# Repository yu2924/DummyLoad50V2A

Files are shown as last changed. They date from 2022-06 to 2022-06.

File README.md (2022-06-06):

# Dummy Load 50V2A

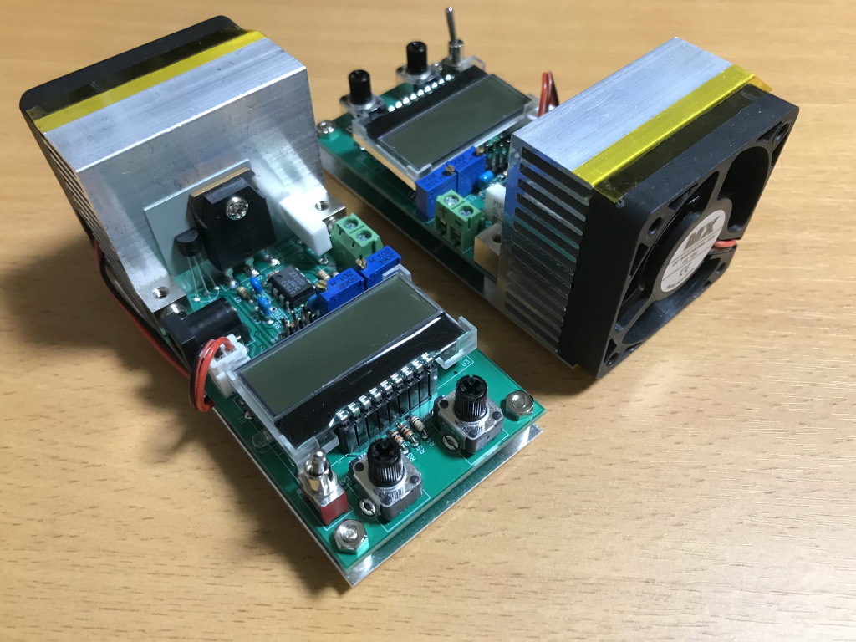
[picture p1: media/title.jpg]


ハードウェアプロジェクト**Dummy Load 50V2A**のデザインについてまとめます。

## 1. 概要

**Dummy Load 50V2A**は電源回路の負荷テストなどに便利な、定電流電子負荷装置です。
AVRマイコンを使用して電圧・電流・温度をモニタします。

* 最大定格DC50V、2A、50W程度
* 電圧モニタ分解能: 0.1V
* 電流モニタ分解能: 1mA
* 温度モニタ分解能: 1℃
* 電源: DC9～12V 100mA程度
* 動作中の電圧・電流・温度をモニタしながら、負荷電流をコース・ファインの2つのツマミで設定
* 負荷のON/OFFスイッチ

## 2. ツールとマテリアル

**ソフトウェアツール**
* 回路作図: [BSch3V](https://www.suigyodo.com/online/schsoft.htm) 0.83.05
* PCB設計: [KiCad](https://www.kicad.org/) 5.1
* ファームウェア開発: Atmel Studio 7 ([Microchip Studio 7](https://www.microchip.com/en-us/tools-resources/develop/microchip-studio))
* I2Cライブラリ: USI_TWI_Master ([TinyWireM](https://github.com/adafruit/TinyWireM))
* その他作図: [Inkscape](https://inkscape.org/) 1.1

**ハードウェアツール**
* AVRプログラマ: Atmel AVRISP mkIIまたは同等品
* 電圧計・電流計: 電圧と電流の読み取り値の比較基準に信頼できるものが必要です。とりあえず3 1/2桁のDMMでOKです。

**その他**
* ハンダとハンダゴテ、ニッパーとラジオペンチ、ヤスリ、タップとタップハンドル、等々
* スペーサー、ネジ、ワッシャー、アルミ板、等々

**※AVR開発環境のアップデート**
2022-05-31現在、AVRISP mkIIが既にディスコンということもあり、[MPLAB X IDE](https://www.microchip.com/en-us/tools-resources/develop/mplab-x-ide)と[MPLAB SNAP](https://www.microchip.com/en-us/development-tool/PG164100)への移行が良さそうです。Atmel Studioと同じ[Atmel AVR GNU Toolchain](https://www.microchip.com/en-us/tools-resources/develop/microchip-studio/gcc-compilers)も利用できるようです。

## 3. 回路の略解

[回路図](media/DummyLoad50V2A.pdf)

部品は概ね[秋月電子通商](https://akizukidenshi.com/)で購入できるものを中心に選んでいます。

**電子負荷**
オペアンプとMOSFETを使った電流シンクです。
オペアンプは単電源動作で0V入力できるものから広く選べますが、低オフセットのものが望ましいです。
MOSFETも特定の型番に限らず、定格電圧・電流、許容損失、熱抵抗、Vth(on)などの条件に見合ったものの中から広く選べると思います。

コース・ファインの2つのツマミで制御電圧を合成し、負荷電流を設定します。
回路図中480k～∞としている抵抗はオペアンプのオフセットを相殺するためのオプションであり、設定電流を0mAまで絞り込めない場合に追加します。

:bulb:このデザインは定電流負荷ですが、別のアイデアとして基準電圧をターゲット端子から取れば負荷電流が電圧に比例するオーム負荷となります。

**モニタ**
0～50Vの範囲を0.1Vの分解能で表示、オフセット調節を省略可、という条件で部品を選定しました。

* [AVR ATtiny85](https://www.microchip.com/en-us/product/ATtiny85)
* [外付け16bit 2ch ADC MCP3426](https://www.microchip.com/en-us/product/MCP3426)
* [温度センサ MCP9700A](https://www.microchip.com/en-us/product/MCP9700A)
* [LCDモジュール AQM1602Y-FLW-FBW](https://akizukidenshi.com/catalog/g/gP-12619/)

外付けADCを電圧・電流に、内蔵ADCを温度センサにそれぞれ割り当てます。  
AVRマイコンをLCDモジュールの真下に配置するために実装高さを抑え、[丸ピンＩＣソケット RI-01S-SG/4.2SMT](https://akizukidenshi.com/catalog/g/gP-12368/)を基板に埋め込むように実装します。

**ファームウェア**
内蔵のUSIユニットをI2C動作させるために、TinyWireMライブラリに同梱のUSI_TWI_Masterを利用します。TinyWireMはArduinoのライブラリですが、USI_TWI_MasterはArduinoに依存しません。

**放熱**
ヒートシンクの選択は厳密な熱設計に基づくものではありません。市販の電子負荷装置の中で定格50～100W程度のものに注目し、ワット当たりに必要なサイズを大雑把に見積もったものです。
Amazonで購入した詳細不明なアルミ製ヒートシンクと5cm角の12V DCファンを使用して、強制空冷としています。DCファンは3Dプリンタ向けの製品のようでした。

## 4. 組み立て

[ケガキ図](drawings/draft.svg)

ベースには50×100mm、t=1.0のアルミ板を使用しています。

1. パワーMOSFET以外の部品を基板に実装する。
2. 50mm角のヒートシンクにはM3タップを立て、10mm角の垂直取付用ブロックを使って基板と繋ぐ。
3. パワーMOSFETをヒートシンクに取り付け、基板にはんだ付けする。
4. 50×100mmのアルミ板ベースの上に5mmスペーサーを併用して基板とヒートシンクを固定する。
5. ヒートシンクにファンをテープで固定し、基板へコネクタを繋ぐ。
6. AVRマイコンとLCDを順にソケットに挿し込む。
7. AVRライタをISPピンヘッダに接続し、電源を接続してファームウェアを書き込む。
8. 適当な電圧・電流源を接続し、信頼できる電圧・電流計と表示値が一致するように多回転トリマをそれぞれ調節する。

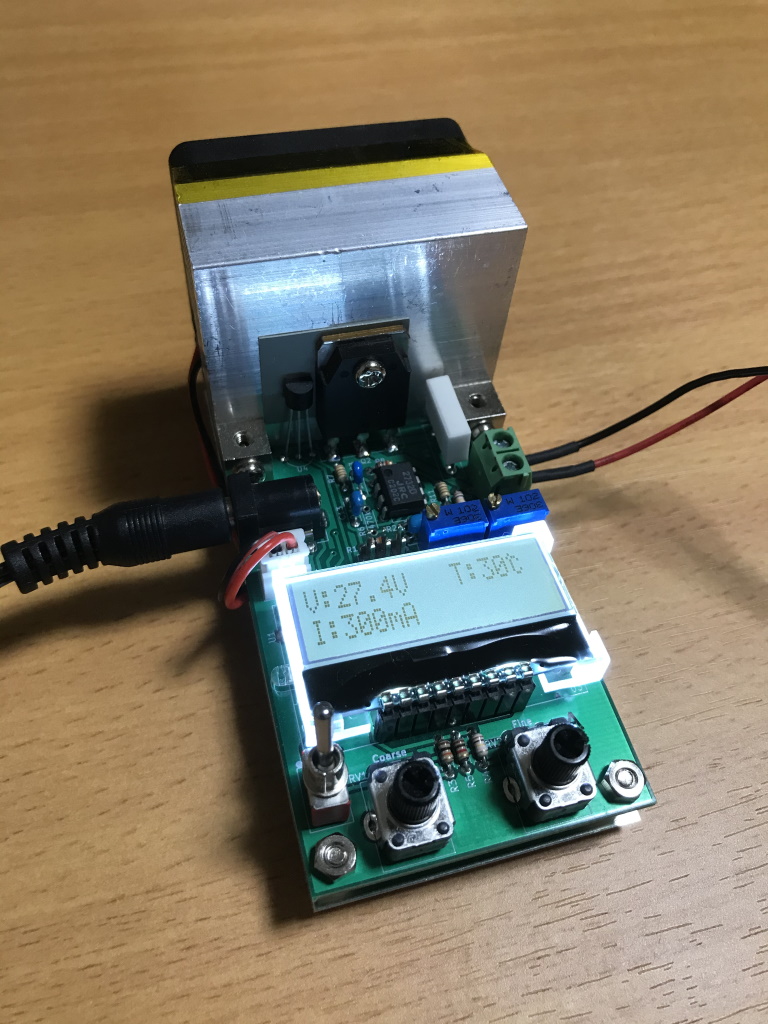
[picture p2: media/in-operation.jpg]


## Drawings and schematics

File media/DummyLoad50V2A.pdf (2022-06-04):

# Vdd VDD

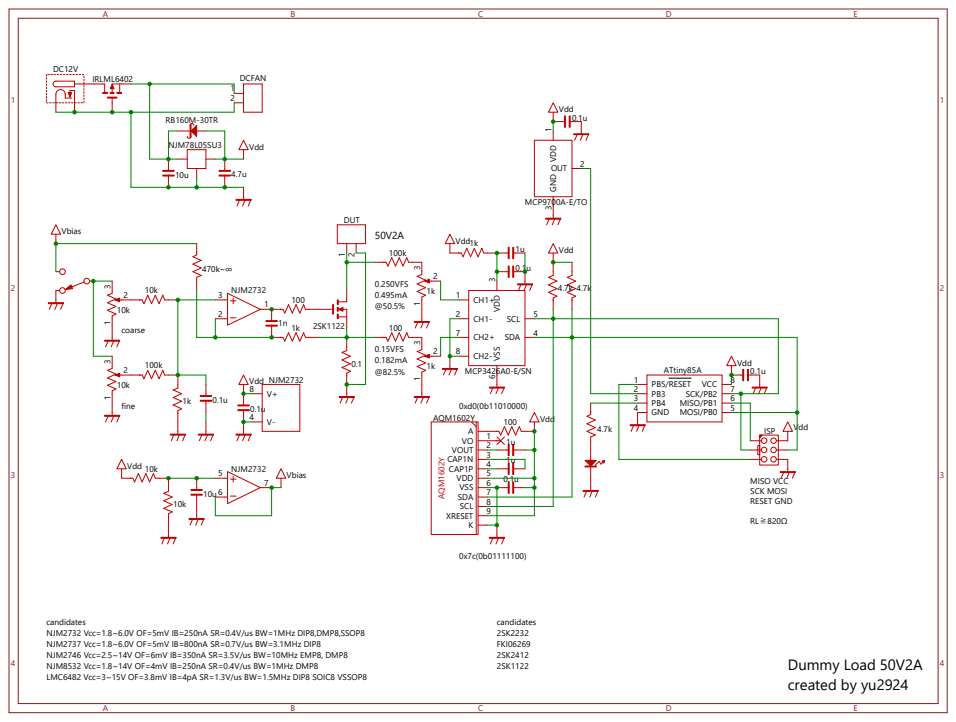
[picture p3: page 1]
Dummy Load 50V2A created by yu2924; MISO VCC SCK MOSI RESET GND; candidates 2SK2232 FKI06269 2SK2412 2SK1122; 0.250VFS 0.495mA @50.5%; 0.15VFS 0.182mA @82.5%; coarse; fine; IRLML6402; DCFAN; NJM78L05SU3; NJM2732; DUT; Vbias; Vdd 100k; Vdd; XRESET; SCL; SDA; VSS; VDD; CAP1P; CAP1N; VOUT; K AQM¹⁶⁰²Y; AQM1602Y; ISP; SDA 4; SCL 5 VDD; 3 VSS 6; MCP3426A0-E/SN; 1 GND; 3 OUT 2; MCP9700A-E/TO; 1k Vdd; Vdd NJM2732; VCC; PB5/RESET 1; GND 4; SCK/PB2; MISO/PB1; MOSI/PB0; ATtiny85A

candidates
NJM2732 Vcc=1.8~6.0V OF=5mV IB=250nA SR=0.4V/us BW=1MHz DIP8,DMP8,SSOP8
NJM2737 Vcc=1.8~6.0V OF=5mV IB=800nA SR=0.7V/us BW=3.1MHz DIP8
NJM2746 Vcc=2.5~14V OF=6mV IB=350nA SR=3.5V/us BW=10MHz EMP8, DMP8
NJM8532 Vcc=1.8~14V OF=4mV IB=250nA SR=0.4V/us BW=1MHz DMP8
LMC6482 Vcc=3~15V OF=3.8mV IB=4pA SR=1.3V/us BW=1.5MHz DIP8 SOIC8 VSSOP8

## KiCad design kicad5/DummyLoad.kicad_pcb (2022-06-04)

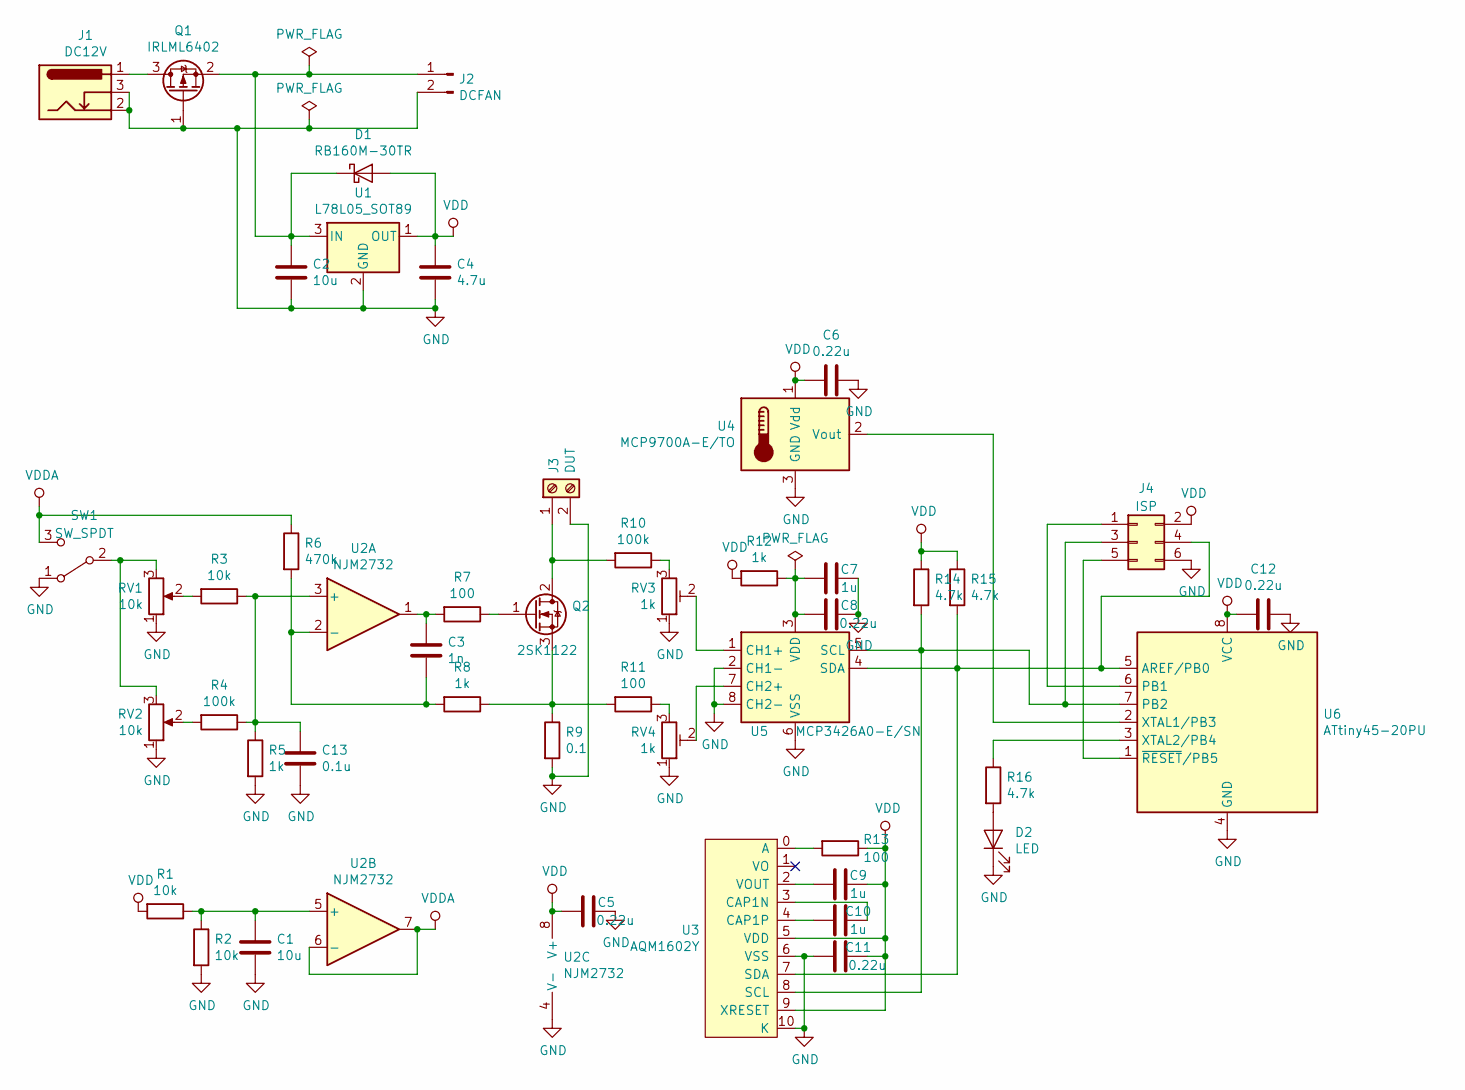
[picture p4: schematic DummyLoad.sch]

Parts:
C1: 10u; C_Disc_D4.7mm_W2.5mm_P5.00mm
C2: 10u; C_1206_3216Metric_Pad1.42x1.75mm_HandSolder
C3: 1n; C_Disc_D4.3mm_W1.9mm_P5.00mm
C4: 4.7u; C_0805_2012Metric_Pad1.15x1.40mm_HandSolder
C5, C6, C8, C11, C12: 0.22u; C_0603_1608Metric_Pad1.05x0.95mm_HandSolder
C7, C9, C10: 1u; C_0603_1608Metric_Pad1.05x0.95mm_HandSolder
C13: 0.1u; C_Disc_D4.3mm_W1.9mm_P5.00mm
D1: RB160M-30TR; D_SOD-123
D2: LED; LED_D3.0mm_Horizontal_O3.81mm_Z2.0mm
J1: DC12V; BarrelJack_Horizontal
J2: DCFAN; JST_XH_B2B-XH-A_1x02_P2.50mm_Vertical
J3: DUT; Terminal-2P
J4: ISP; PinHeader_2x03_P2.54mm_Vertical
Q1: IRLML6402; SOT-23
Q2: 2SK1122; TO-3P-3_Vertical
R1, R2, R3: 10k; R_Axial_DIN0204_L3.6mm_D1.6mm_P5.08mm_Horizontal
R4, R10: 100k; R_Axial_DIN0204_L3.6mm_D1.6mm_P5.08mm_Horizontal
R5, R8, R12: 1k; R_Axial_DIN0204_L3.6mm_D1.6mm_P5.08mm_Horizontal
R6: 470k; R_Axial_DIN0204_L3.6mm_D1.6mm_P5.08mm_Horizontal
R7, R11, R13: 100; R_Axial_DIN0204_L3.6mm_D1.6mm_P5.08mm_Horizontal
R9: 0.1; R_Box_L13.0mm_W4.0mm_P9.00mm
R14, R15, R16: 4.7k; R_Axial_DIN0204_L3.6mm_D1.6mm_P5.08mm_Horizontal
RV1, RV2: 10k; Potentiometer_Alps_RK09K_Single_Vertical
RV3, RV4: 1k; Potentiometer_Bourns_3296W_Vertical
SW1: SW_SPDT; SPDT-PCB
U1: L78L05_SOT89; SOT-89-3
U2: NJM2732; DIP-8_W7.62mm
U3: AQM1602Y
U4: MCP9700A-E/TO; TO-92_Inline_Wide
U5: MCP3426A0-E/SN; SOIC-8_3.9x4.9mm_P1.27mm
U6: ATtiny45-20PU; DIP-8_W7.62mm-LoProf

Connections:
GND: C1.2, C2.2, C4.2, C5.2, C6.2, C7.2, C8.2, C11.2, C12.2, C13.2, D2.1 (K), J1.2, J1.3, J2.2, J3.2, J4.6, Q1.1 (G), R2.2, R5.2, R9.2, RV1.0, RV1.1, RV2.0, RV2.1, RV3.1, RV4.1, SW1.1 (A), U1.2 (GND), U2.4 (V-), U3.6 (VSS), U3.10 (K), U4.3 (GND), U5.2 (CH1-), U5.6 (VSS), U5.8 (CH2-), U6.4 (GND)
unnamed: C1.1, R1.1, R2.1, U2.5 (+)
unnamed: C2.1, D1.1 (K), J2.1, Q1.2 (S), U1.3 (IN)
unnamed: C3.1, R7.2, U2.1
unnamed: C3.2, R6.2, R8.2, U2.2 (-)
unnamed: C7.1, C8.1, R12.1, U5.3 (VDD)
unnamed: C9.2, U3.2 (VOUT)
unnamed: C10.1, U3.3 (CAP1N)
unnamed: C10.2, U3.4 (CAP1P)
unnamed: C13.1, R3.1, R4.1, R5.1, U2.3 (+)
unnamed: D2.2 (A), R16.2
unnamed: J1.1, Q1.3 (D)
unnamed: J3.1, Q2.2 (D), R10.2
unnamed: J4.1, U6.6 (PB1)
unnamed: J4.3, R14.2, U3.8 (SCL), U5.5 (SCL), U6.7 (PB2)
unnamed: J4.4, R15.2, U3.7 (SDA), U5.4 (SDA), U6.5 (AREF/PB0)
unnamed: J4.5, U6.1 (~RESET~/PB5)
unnamed: Q2.1 (G), R7.1
unnamed: Q2.3 (S), R8.1, R9.1, R11.2
unnamed: R3.2, RV1.2
unnamed: R4.2, RV2.2
unnamed: R10.1, RV3.3
unnamed: R11.1, RV4.3
unnamed: R13.2, U3.0 (A)
unnamed: R16.1, U6.3 (XTAL2/PB4)
unnamed: RV1.3, RV2.3, SW1.2 (B)
unnamed: RV3.2, U5.1 (CH1+)
unnamed: RV4.2, U5.7 (CH2+)
unnamed: U4.2 (Vout), U6.2 (XTAL1/PB3)
VDD: C4.1, C5.1, C6.1, C9.1, C11.1, C12.1, D1.2 (A), J4.2, R1.2, R12.2, R13.1, R14.1, R15.1, U1.1 (OUT), U2.8 (V+), U3.5 (VDD), U3.9 (XRESET), U4.1 (Vdd), U6.8 (VCC)
VDDA: R6.1, SW1.3 (C), U2.6 (-), U2.7

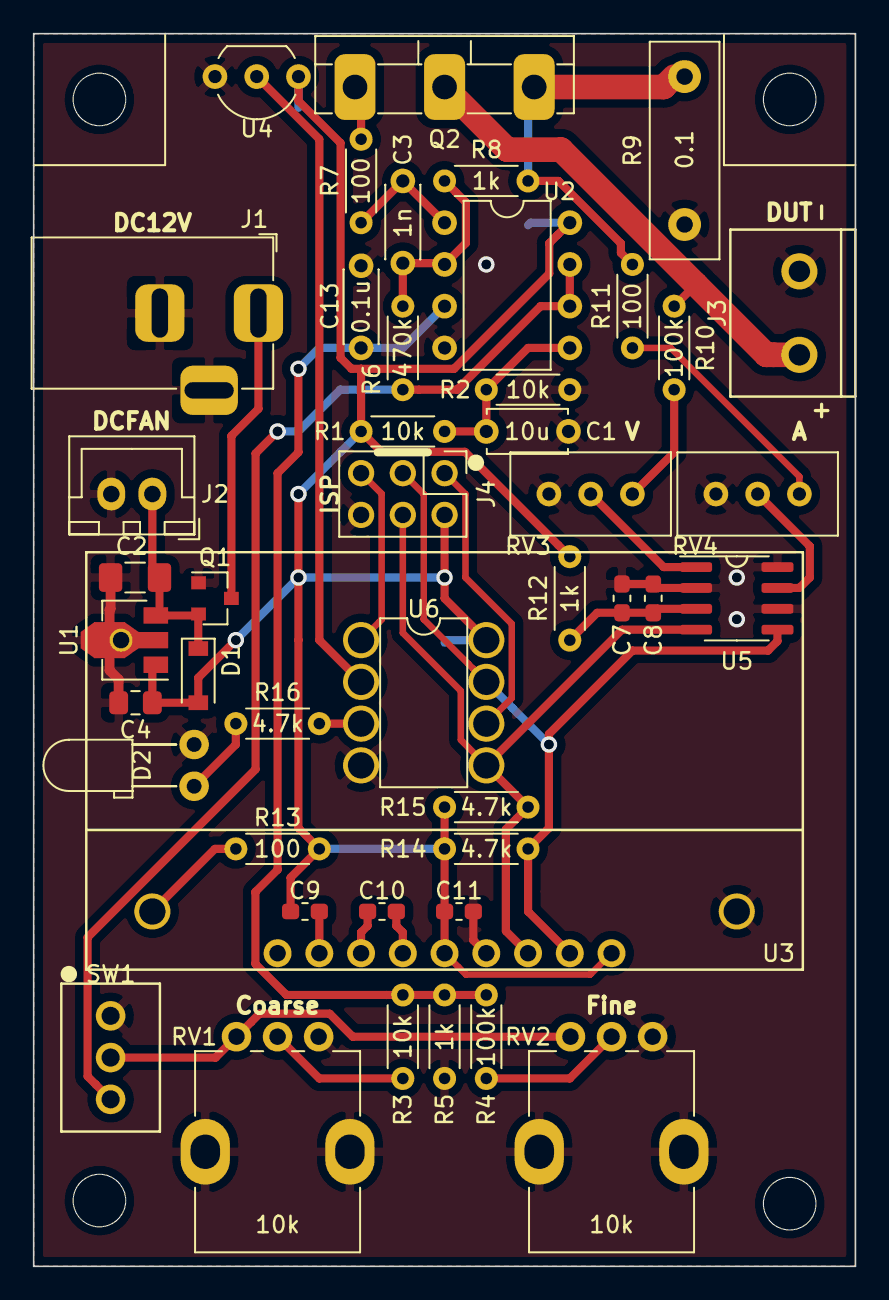
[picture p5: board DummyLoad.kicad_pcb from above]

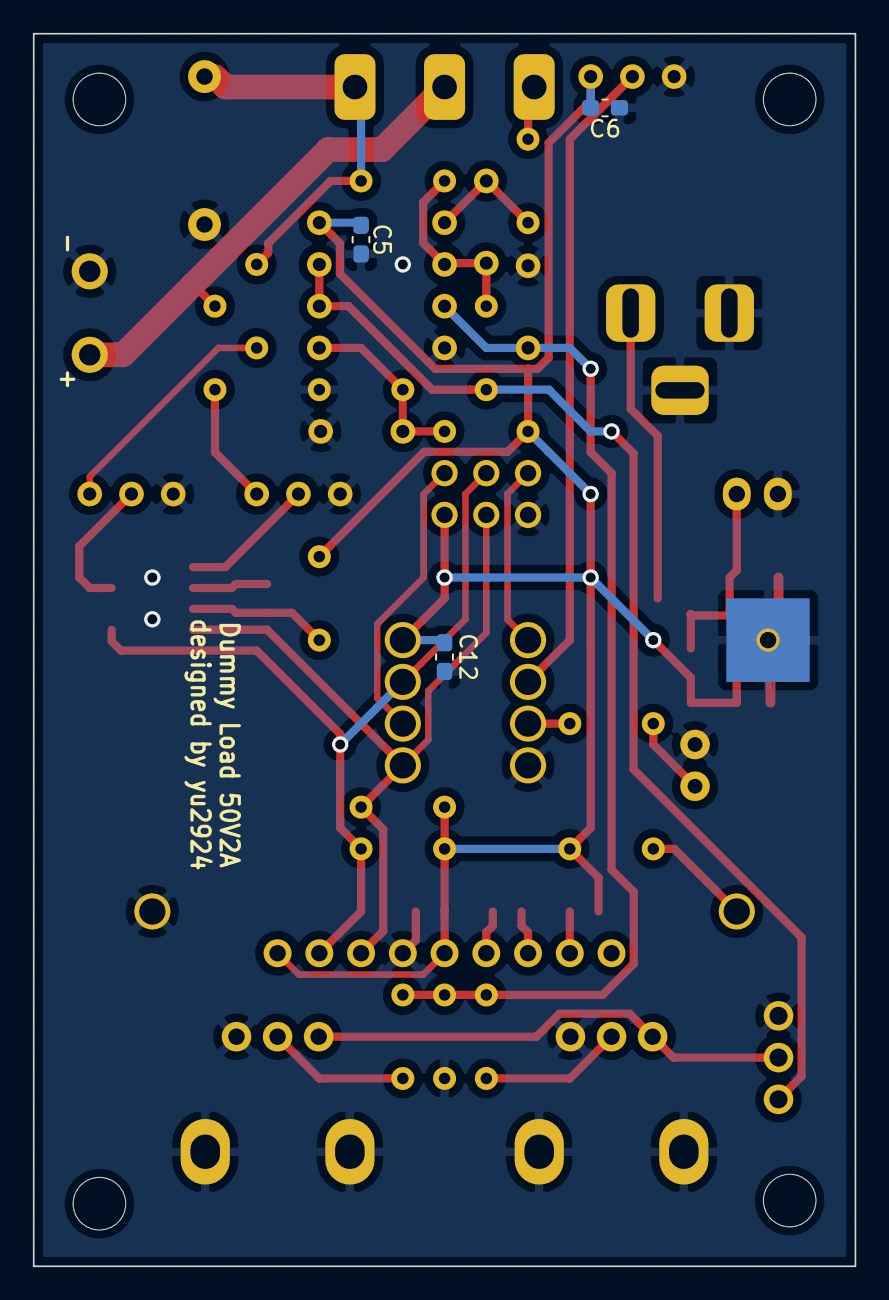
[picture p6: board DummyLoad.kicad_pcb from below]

Board: 2 copper layers, 50.0 x 75.0 mm, 48 parts (3 on the bottom side), 31 nets.

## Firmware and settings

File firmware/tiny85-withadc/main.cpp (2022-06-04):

/*
 * tiny85-withadc.cpp
 *
 * Created: 2019/08/12 0:39:17
 * Author : yu2924
 */ 

#include <avr/io.h>
#include <avr/interrupt.h>
#include <avr/sleep.h>
#include <util/delay.h>
// to use float with printf, requires linker options: -Wl,-u,vfprintf -lprintf_flt -lm
#include <stdio.h>
#include "USI_TWI_Master.h"
#include "MCP342x.h"
#include "ST7032i.h"

inline uint8_t getbit(volatile uint8_t& port, uint8_t bit) {return (port >> bit) & 0x01;}
inline void setbit(volatile uint8_t& port, uint8_t bit, uint8_t v) {port = (port & (uint8_t)~(1 << bit)) | (v << bit);}
	
inline int roundd2ip(double v) { return (int)(v + 0.5); }
inline int16_t absi16(int16_t v) { return (0 <= v) ? v : -v; }

struct AverageBuffer8ui
{
	uint16_t totalsum;
	uint8_t buffer[4];
	uint8_t pos;
	uint8_t push(uint8_t vnew)
	{
		uint8_t vlast = buffer[pos & 0x03];
		totalsum -= vlast;
		buffer[pos & 0x03] = vnew;
		totalsum += vnew;
		pos ++;
		return (uint8_t)(totalsum >> 2);
	}
};

struct AverageBuffer14i
{
	int16_t totalsum;
	int16_t buffer[4];
	uint8_t pos;
	int16_t push(int16_t vnew)
	{
		int16_t vlast = buffer[pos & 0x03];
		totalsum -= vlast;
		buffer[pos & 0x03] = vnew;
		totalsum += vnew;
		pos ++;
		return totalsum >> 2;
	}
};

#define LED_PORT PORTB
#define LED_BIT PB4

static const uint8_t CG_CDEG[] =
{
	0b00001000,
	0b00010110,
	0b00001001,
	0b00001000,
	0b00001000,
	0b00001001,
	0b00000110,
	0b00000000,
};

int main(void)
{
	// clock prescaler
	CLKPR = (1<<CLKPCE); // enable change
	CLKPR = (0b0000<<CLKPS0); // divisor=1 (8MHz)
	// PortB
	DDRB = (1<<DDB4); // LED output: PB4
	PORTB = (1<<PB5)|(1<<PB1); // pull-up enabled: unused pins PB1, PB5
	// ADC
	ADMUX = (0<<REFS0)|(1<<ADLAR)|(0<<REFS2)|(0b0011<<MUX0); // vref=Vcc, alignment=left-justified, mux=ADC3(PB3)
	ADCSRA = (1<<ADEN)|(0<<ADATE)|(0<<ADIF)|(0<<ADIE)|(0b110<<ADPS0); // ADC=enabled, auto-trigger=disabled, interrupt=disabled, prescaler=1/64 (125kHz)
	ADCSRB = (0<<BIN)|(0<<IPR)|(0b000<<ADTS0); // bipolar=no, polarity-reversal=no, triggersource=freerunning
	DIDR0 = (1<<ADC3D); // digital-input-disabled-ADC3(PB3)=yes
	// timer1
	TCCR1 = (1<<CTC1)|(0b1111<<CS10); // enable CTC, divisor=16384 (488.3Hz)
	GTCCR = 0;
	OCR1A = 24; // tick = 20.35Hz (fire interrupt)
	OCR1C = 24; // tick = 20.35Hz (reset counter)
	TIMSK = (1<<OCIE1A); // enable interrupt
	PLLCSR = 0; // no PLL
	// i2c
	USI_TWI_Master_Initialise();
	MCP342x mcp3426 = {};
	ST7032i st7032i = {};
	mcp3426.initialize(MCP342X_I2CADDR);
	st7032i.initialize(ST7032_I2CADDR, 0, 35); // AQM1602XA or AQM1602Y, 5V
	st7032i.writeCommand(ST7032CmdSetDDRAMAddr | ST7032DDRAMOffsetL1);
	st7032i.writeString("Dummy Load 50V2A");
	st7032i.writeCommand(ST7032CmdSetDDRAMAddr | ST7032DDRAMOffsetL2);
	st7032i.writeString("by yu2924");
	st7032i.writeCommand(ST7032CmdSetCGRAMAddr | 8); // for char_code='\x1', char_height=8
	st7032i.writeData(CG_CDEG, sizeof(CG_CDEG));
	for(int i = 0; i < 2; i ++)
	{
		_delay_ms(500);
		setbit(LED_PORT, LED_BIT, 1);
		_delay_ms(500);
		setbit(LED_PORT, LED_BIT, 0);
	}
	st7032i.writeCommand(ST7032CmdClearDisplay);
	// run
	// T:
	//   MCP9700A: Vmeas=0.5+T/100 => Tmeas=(Vmeas-0.5)*100
	//   ADC: Vmeas/5=vcode/255 => Vmeas=5*vcode/255=vcode/51, vcode=255*Vmeas/5=Vmeas*51
	//   Tmeas=(vcode/51-0.5)*100
	//   vcode=(0.5+Tmeas/100)*51
	// V:
	//   Vfs=0.25V
	//   ADC: Vmeas/50=vcode/8191
	//   Vmeas=50*vcode/8191=vcode/163.82
	//   vcode=8191*Vmeas/50=Vmeas*163.82
	//
	// I:
	//   Vfs=0.15V
	//   ADC: Imeas/1.2=vcode/(8191*0.15/0.25)=vcode/4914.6
	//   Imeas=1.2*vcode/4914.6=vcode/4095.5
	//   vcode=4914.6*Imeas/1.2=Imeas*4095.5
	static const int Tht = 60;
	static const double Av = 1.0 / 163.82;
	static const double Ai = 1000.0 / 2800.0; // 4095.5;
	AverageBuffer8ui averaget = {};
	AverageBuffer14i averagev = {};
	AverageBuffer14i averagei = {};
	char str[16];
	bool flipch = false;
	ADCSRA |= (1<<ADSC); // trigger internal ADC
	mcp3426.StartConversion(MCP342X_CH1 | MCP342X_ONESHOT | MCP342X_SIZE_14 | MCP342X_PGA_X8);
	sei();
	set_sleep_mode(SLEEP_MODE_IDLE);
	sleep_mode();
	while(1)
	{
		uint8_t vt = averaget.push(ADCH);
		int tmeas = roundd2ip(((double)vt / 51.0 - 0.5) * 100.0);
		sprintf(str, "T:%d\x1 ", tmeas);
		st7032i.writeCommand(ST7032CmdSetDDRAMAddr | (ST7032DDRAMOffsetL1 + 10));
		st7032i.writeString(str);
		setbit(LED_PORT, LED_BIT, (Tht <= tmeas) ? 1 : 0);
		ADCSRA |= (1<<ADSC); // trigger internal ADC
		if(!flipch)
		{
			int16_t v; uint8_t cfg; mcp3426.GetResult14(&v, &cfg);
			v = averagev.push(absi16(v));
			sprintf(str, "V:%4.1fV ", (double)v * Av);
			// sprintf(str, "V:%4.1fV %d ", (double)v * Av, v);
			st7032i.writeCommand(ST7032CmdSetDDRAMAddr | ST7032DDRAMOffsetL1);
			st7032i.writeString(str);
			mcp3426.StartConversion(MCP342X_CH2 | MCP342X_ONESHOT | MCP342X_SIZE_14 | MCP342X_PGA_X8);
		}
		else
		{
			int16_t v; uint8_t cfg; mcp3426.GetResult14(&v, &cfg);
			v = averagei.push(absi16(v));
			sprintf(str, "I:%2dmA ", roundd2ip((double)v * Ai));
			// sprintf(str, "I:%2dmA %d ", roundd2ip((double)v * Ai), v);
			st7032i.writeCommand(ST7032CmdSetDDRAMAddr | ST7032DDRAMOffsetL2);
			st7032i.writeString(str);
			mcp3426.StartConversion(MCP342X_CH1 | MCP342X_ONESHOT | MCP342X_SIZE_14 | MCP342X_PGA_X8);
		}
		flipch = !flipch;
		sleep_mode();
	}
	return 0;
}

ISR(TIM1_COMPA_vect)
{
}

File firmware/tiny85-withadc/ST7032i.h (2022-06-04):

/*
 * ST7032i.h
 *
 * Created: 2018/02/17 5:29:05
 *  Author: yu2924
 */ 

#ifndef include_ST7032_h
#define include_ST7032_h

#include <stdint.h>

#if defined(__cplusplus)
#define ST7032API extern "C"
#else
#define ST7032API
#endif

#define ST7032_I2CADDR			0b01111100

#define ST7032CoContinue		0b10000000
#define ST7032CoFinal			0b00000000
#define ST7032RSData			0b01000000
#define ST7032RSCommand			0b00000000

// commands
#define ST7032CmdClearDisplay	0b00000001
#define ST7032CmdReturnHome		0b00000010
#define ST7032CmdEntryMode		0b00000100
#define ST7032CmdDisplay		0b00001000
#define ST7032CmdShift			0b00010000
#define ST7032CmdFunction		0b00100000
#define ST7032CmdSetCGRAMAddr	0b01000000
#define ST7032CmdSetDDRAMAddr	0b10000000
#define ST7032CmdIntOscFreq		0b00010000 // extension IS=1
#define ST7032CmdPowerIconCtrl	0b01010000 // extension IS=1
#define ST7032CmdFollowerCtrl	0b01100000 // extension IS=1
#define ST7032CmdContrast		0b01110000 // extension IS=1

// flags for ST7032CmdEntryMode
#define ST7032EntryModePerform	0b01
#define ST7032EntryModeInc		0b10
#define ST7032EntryModeDec		0b00

// flags for ST7032CmdDisplay
#define ST7032DisplayOn			0b100
#define ST7032DisplayOff		0b000
#define ST7032CursorOn			0b010
#define ST7032CursorOff			0b000
#define ST7032BlinkOn			0b001
#define ST7032BlinkOff			0b000

// flags for ST7032CmdShift
#define ST7032ShiftScreen		0b1000
#define ST7032ShiftCursor		0b0000
#define ST7032ShiftRight		0b0100
#define ST7032ShiftLeft			0b0000

// flags for ST7032CmdFunction
#define ST7032DataLength8		0b10000
#define ST7032DataLength4		0b00000
#define ST7032LineNumber2		0b01000
#define ST7032LineNumber1		0b00000
#define ST7032DoubleHeight		0b00100
#define ST7032ExtensionInst		0b00001
#define ST7032NormalInst		0b00000

// flags for ST7032CmdSetDDRAMAddr
#define ST7032DDRAMAddrMask		0b1111111
#define ST7032DDRAMOffsetL1		0x00
#define ST7032DDRAMOffsetL2		0x40

// flags for ST7032CmdIntOscFreq
#define ST7032OscFreqBias4th	0b1000
#define ST7032OscFreqBias5th	0b0000
#define ST7032OscFreqMask		0b0111

// flags for ST7032CmdPowerIconCtrl
#define ST7032IconDisplayOn		0b1000
#define ST7032IconDisplayOff	0b0000
#define ST7032BoosterOn			0b0100
#define ST7032BoosterOff		0b0000
#define ST7032IconContrastMask	0b0011

// flags for ST7032CmdFollowerCtrl
#define ST7032FollowerOn		0b1000
#define ST7032FollowerOff		0b0000
#define ST7032FollowerMask		0b0111

// flags for ST7032CmdContrast
#define ST7032ContrastMask		0b1111

ST7032API void ST7032Initialize(uint8_t addr, uint8_t bon, uint8_t contrast); // bon=0or1, contrast=0~63 (bon=1 for 5V)
ST7032API void ST7032WriteCommand(uint8_t addr, uint8_t v);
ST7032API void ST7032WriteData(uint8_t addr, const uint8_t* p, uint8_t c);
ST7032API void ST7032WriteString(uint8_t addr, const char* p);

typedef struct ST7032i
{
	uint8_t i2caddress;
#if defined __cplusplus
	void initialize(uint8_t addr, uint8_t bon, uint8_t contrast) { i2caddress = addr; ST7032Initialize(i2caddress, bon, contrast); }
	void writeCommand(uint8_t v) { ST7032WriteCommand(i2caddress, v); }
	void writeData(const uint8_t* p, uint8_t c) { ST7032WriteData(i2caddress, p, c); }
	void writeString(const char* p) { ST7032WriteString(i2caddress, p); }
#endif
} ST7032i;

#endif // include_ST7032_h
